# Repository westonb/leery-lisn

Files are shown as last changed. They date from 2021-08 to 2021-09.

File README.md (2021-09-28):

# leery-lisn
### A open source dual AC LISN with integrated common mode / differential mode separator and transient limiter.

**Schematic [here](doc/lisn-pcb.pdf)**

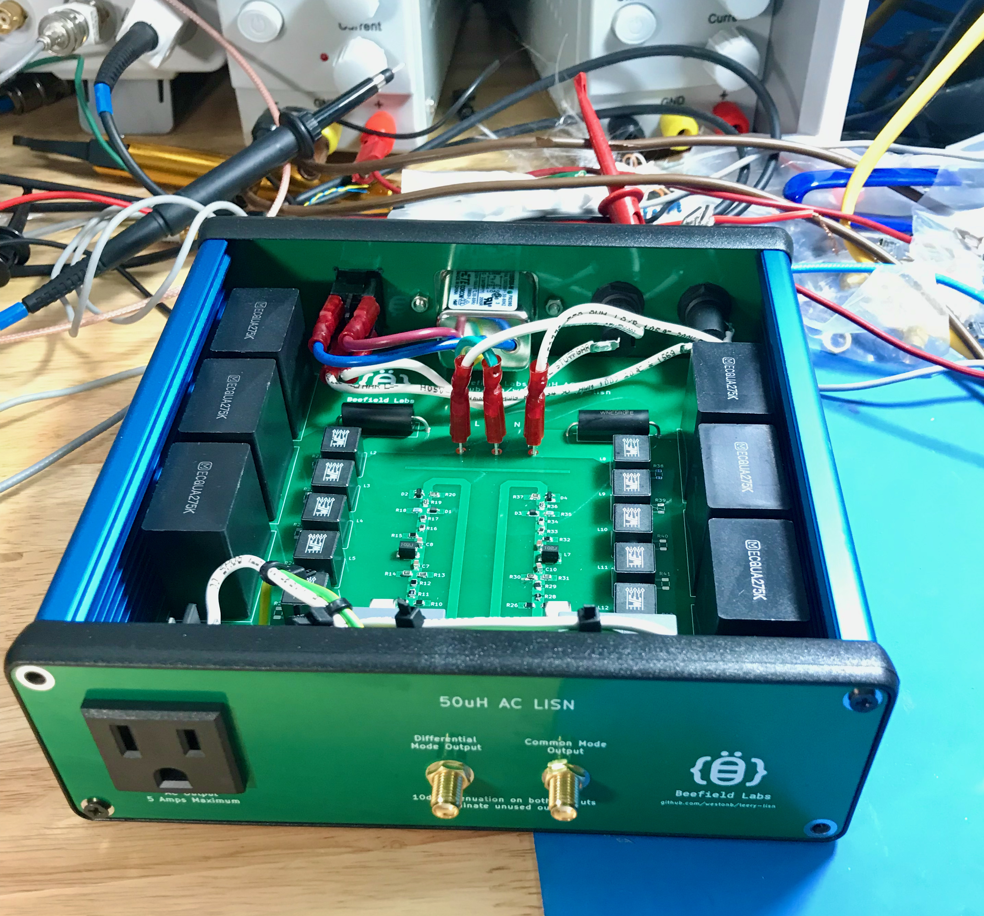
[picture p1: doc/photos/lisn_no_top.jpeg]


## Summary
The leery-lisn is a Line Impedance Stabilization Network (LISN) for pre-compliance conducted EMI measurements of devices that plug into the AC line.
A LISN goes between a device and the AC outlet and provides a known AC line impedance, allowing for repeatable measurements of conducted noise generated by the device.
It also contains circuitry to couple the noise to a 50 ohm RF output to allow for measurement with a spectrum analyzer.

The leery-lisn contains a LISN network on both the neutral and line connections of the AC plug and a common mode / differential mode separator, allowing for measurement of both the differential mode and common mode noise generated by a device.
It also contains a transient limiter to protect a connected spectrum analyzer from transients on the AC line or plugging the LISN into the AC line when the spectrum analyzer is already connected.

The design of the leery-lisn is loosely based on the LISN designs from this [thread](https://www.eevblog.com/forum/projects/5uh-lisn-for-spectrum-analyzer-emcemi-work/) on the EEVBlog forum, as well as the designs for a [common mode / differential mode separator](https://www.eevblog.com/forum/projects/diy-dm-cm-seperator-for-emc-lisn-mate/) and this [transient limiter](https://www.eevblog.com/forum/projects/transient-limiter-for-spectrum-analyzer-protection/).

## Specifications & Operation
The leery-lisn is a 50uH LISN, which is the typical impedance value for conducted emissions testing between 150KHz - 30MHz, as specified in standards such as CISPR16.
The leery-lisn is designed for a maximum input / output voltage of 240V, although the output plug is fixed as a US style 120V plug.
The current rating is 5A RMS.

Due to the transient limiter, the common mode and differential mode outputs have 10dB of attenuation.
For proper separation of the common mode and differential mode signals the unused output should be attenuated into 50 ohms.

The leery-lisn contains 8.1uF of capacitance between each AC leg and ground to decouple the LISN impedance from the impedance of the AC line.
Due to the high ground currents resulting from this capacitance, consider using a isolation transformer between the AC line and the leery-lisn.

## Performance
S21 measurements were taken of the leery-lisn to verify correct operation of the common mode / differential mode separator and impedance measurements were taken to check compliance with CISPR16 standard.

A very cursed adaptor was created to connect the AC output of the LISN to a VNA and measurements were taken with the AC input to the VNA shorted.

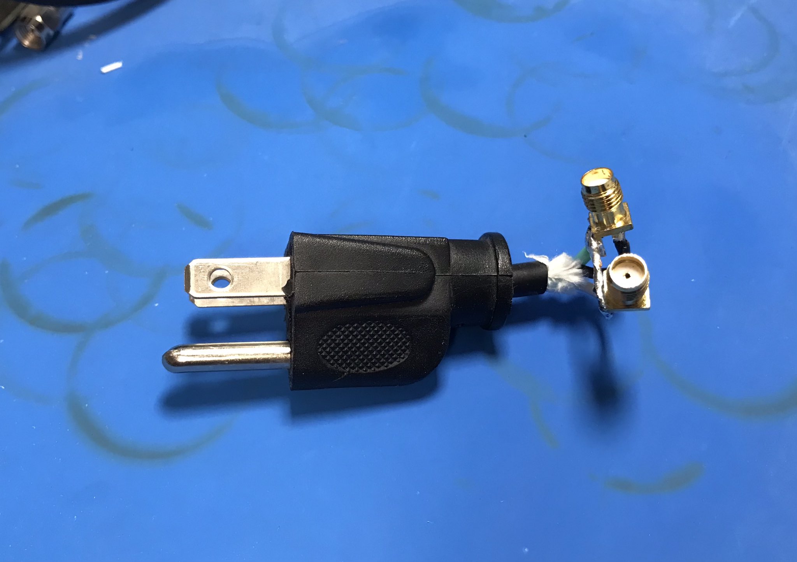
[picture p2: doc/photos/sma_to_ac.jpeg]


The leery-lisn is a three port device, so it can not be fully characterized with a two port VNA.
However, a resistive splitter allows for accurately measuring the common mode S21 and the common mode rejection.

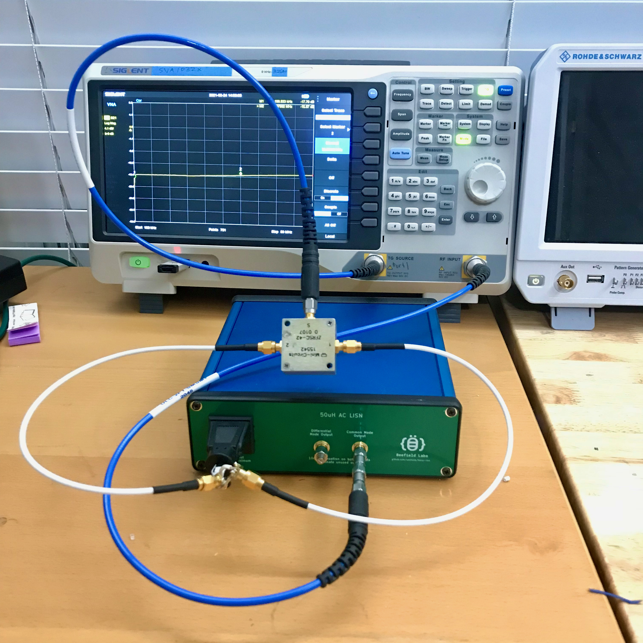
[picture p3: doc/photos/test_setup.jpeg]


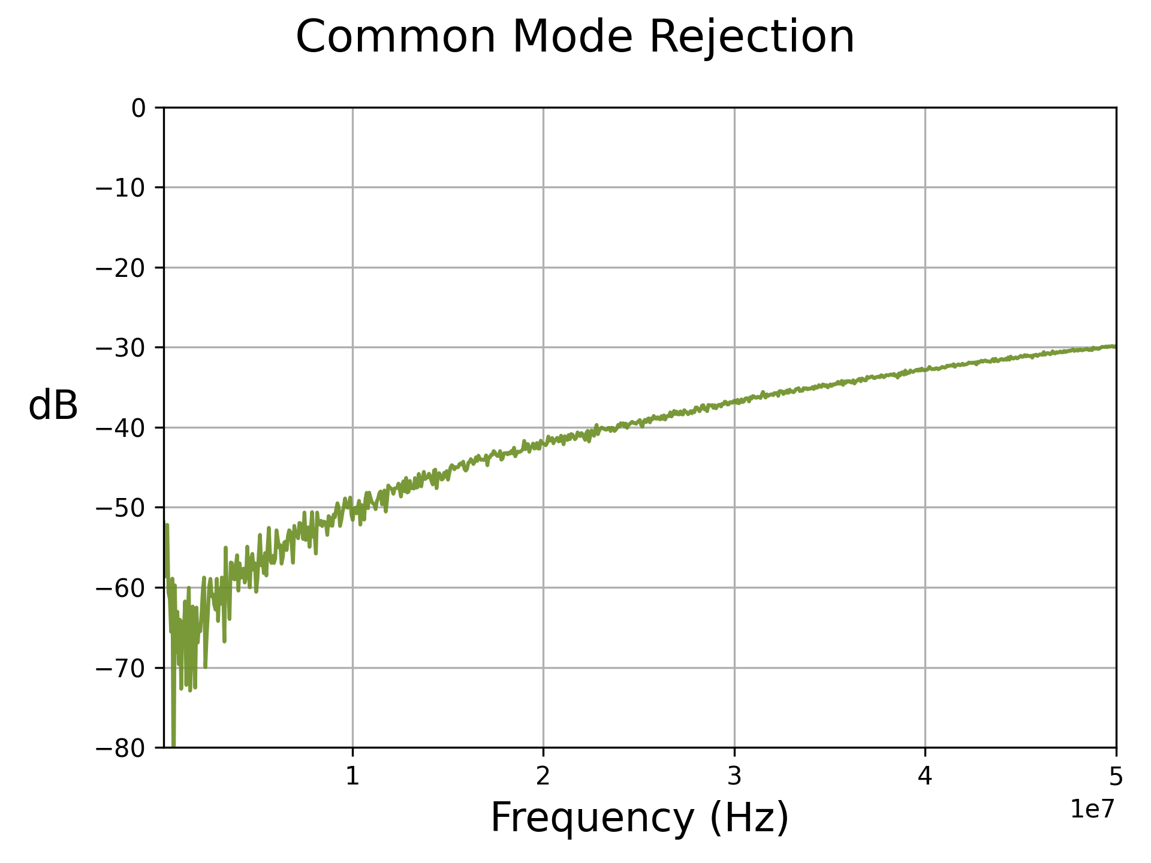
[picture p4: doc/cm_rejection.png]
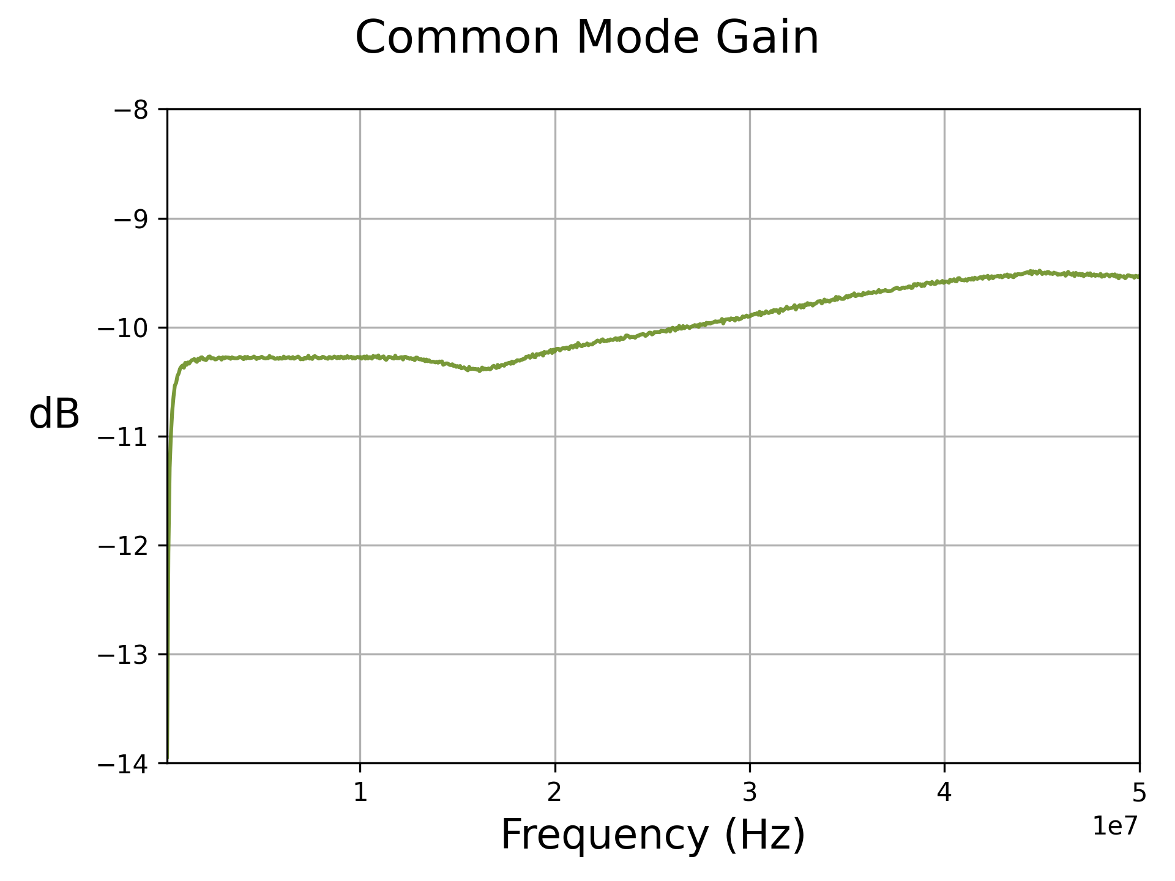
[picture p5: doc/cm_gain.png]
 

If it is assumed that driving one input to the LISN with the other terminated into 50 ohms provides a even split of common mode and differential mode stimulus, the differential mode S21 can also be measured.

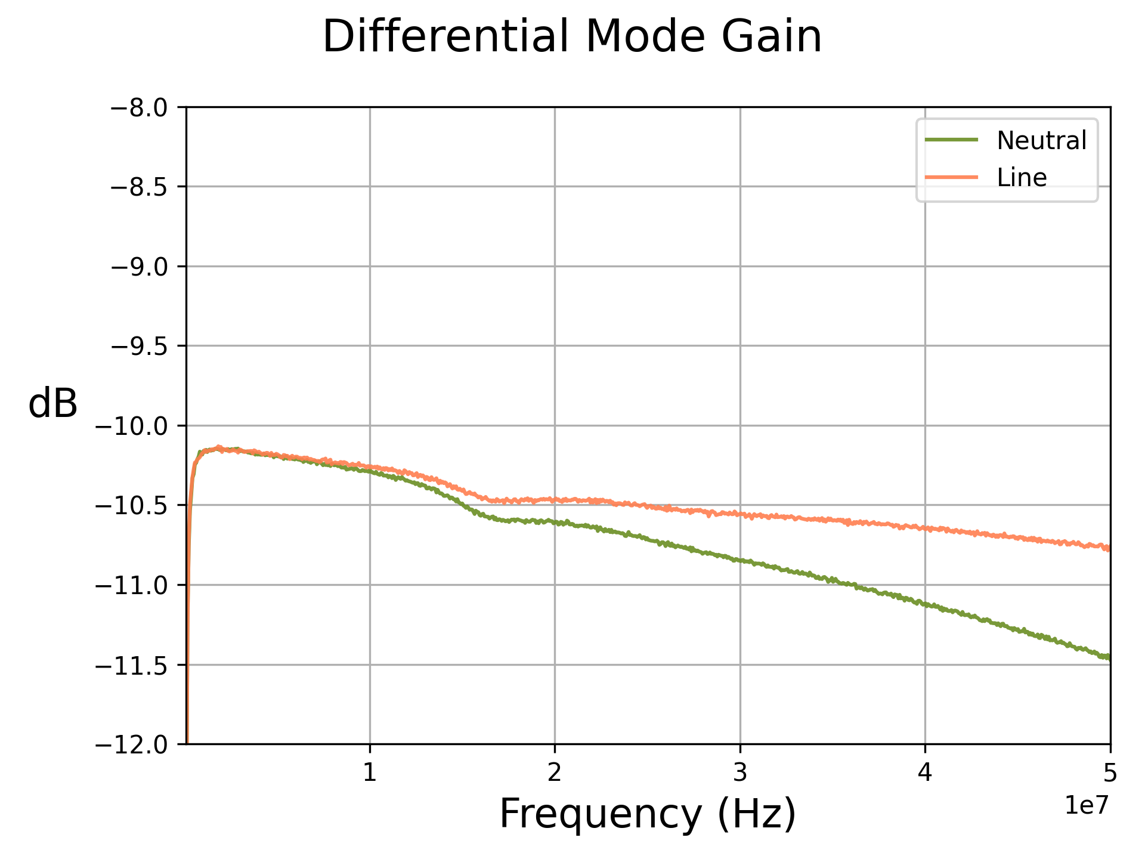
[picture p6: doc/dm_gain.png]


The impedance of the two legs can also be compared against the CISPR16 standard, which provides a table of frequency vs the allowable |Z| and phase of the LISN input impedance.
From the plot below it can be seen that the line leg of the LISN is slightly out of spec above 25MHz due to an extra 2" of wire running between the AC connector and the PCB.
This is also the cause of the difference in the differential mode response for the two inputs of the LISN.
leery-lisn technically does not meet the CISPR16 requirements, but should be close enough for pre-compliance work.
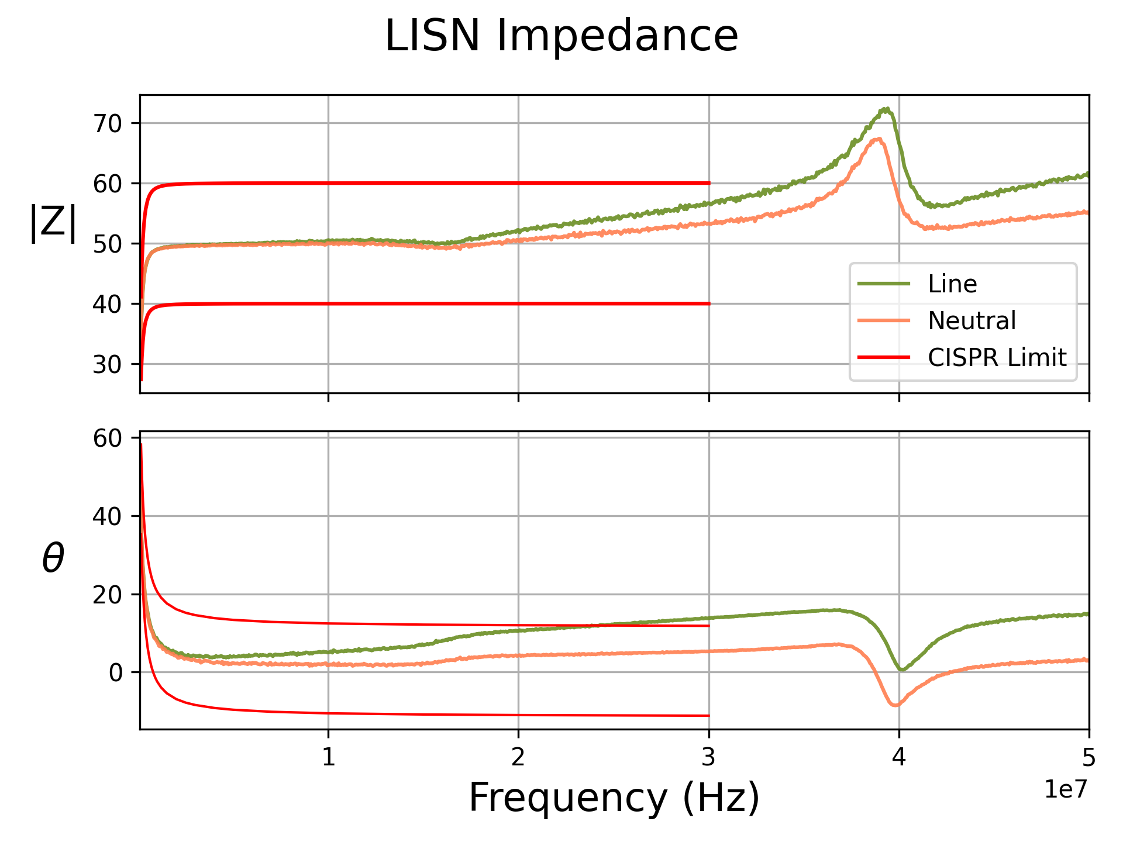
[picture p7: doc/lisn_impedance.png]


## Construction
The leery-lisn is completely open source and the PCB design for the LISN and the front and back panels are provided in this repository.

Parts not on the BOM for the PCB are:

| Description  | Quantity | Part Number |
|---|---|---|
| Enclosure | 1 | 1455T1601BU |
| Fuse Holder  | 2 | 696211001102 |
| AC Outlet | 1 | 3-119-052 |
| Power Switch | 1 | H8550VBBBEN551W |
| AC Inlet | 1 | 1-6609987-4 |

## Improvements
A bleeder resistor should be added across the input capacitors to discharge them.

The impedance of the line side of the LISN is slightly outside of the limits specified in the CISPR16 standards due to the added wire length between the AC plug on the left side of the panel and the line input on the PCB, which is on the right.
The front panel could be redone to reduce this wire length.

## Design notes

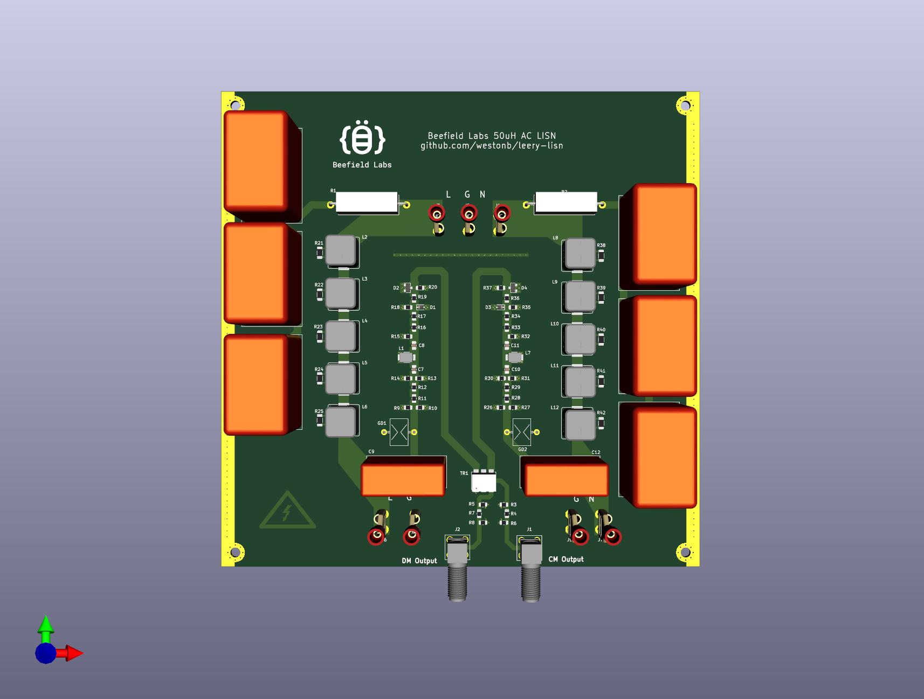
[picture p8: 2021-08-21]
doc/photos/lisn-pcb.jpg

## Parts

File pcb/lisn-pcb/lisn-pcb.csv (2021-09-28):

Ref | Qty | Value | Footprint | Description | MPN
C1, C2, C3, C4, C5, C6, | 6 | 2.7u | Capacitor_THT:C_Rect_L31.5mm_W20.0mm_P27.50mm_MKS4 | Unpolarized capacitor | ECQ-UAAF275K
C7, C8, C10, C11, | 4 | 0.47u | Capacitor_SMD:C_0805_2012Metric | Unpolarized capacitor | 08051C474K4Z2A
C9, C12, | 2 | 0.1u | Capacitor_THT:C_Rect_L26.5mm_W10.5mm_P22.50mm_MKS4 | Unpolarized capacitor | BFC233860104
D1, D3, | 2 | D_TVS | Diode_SMD:D_SOD-323 | Bidirectional transient-voltage-suppression diode | STS321050B100
D2, D4, | 2 | BAV23S | Package_TO_SOT_SMD:SOT-23 | Dual diode, anode/cathode/center | BAV23S,215
GD1, GD2, | 2 | 2045-09-BLF | wbraun_smd:GDT_Bourns_2045 | Gas Discharge Tube with 2 Pins | 2045-09-BLF
H1, H2, H3, H4, | 4 | MountingHole_Pad | wbraun_smd:M3-tight-fit-socket-head | Mounting Hole with connection
J1, J2, | 2 | Conn_Coaxial | Connector_Coaxial:SMA_Amphenol_132203-12_Horizontal | coaxial connector (BNC, SMA, SMB, SMC, Cinch/RCA, ...) | 619540-1
J3, J4, J5, J6, J7, J8, J9, | 7 | 62409-1 | wbraun_smd:62409-1 | Generic connector, single row, 01x01, script generated (kicad-library-utils/schlib/autogen/connector/) | 62409-1
L1, L7, | 2 | 1m | wbraun_smd:L_BOURNS_PM1812 | Inductor | PM1812-102J-RC
L2, L3, L4, L5, L6, L8, L9, L10, L11, L12, | 10 | 10u | wbraun_smd:L_WURTH_WE-HCC-1090 | Inductor symbol for simulation only | 7443331000
R1, R2, | 2 | 5 | Resistor_THT:R_Axial_Power_L20.0mm_W6.4mm_P25.40mm | Resistor | WNE5R0FET
R3, | 1 | 50 | Resistor_SMD:R_0805_2012Metric | Resistor | RNCP0805FTD49R9
R4, R7, | 2 | 0 | Resistor_SMD:R_0805_2012Metric | Resistor | RC0805JR-070RL
R5, R6, R8, | 3 | DNP | Resistor_SMD:R_0805_2012Metric | Resistor
R9, R26, | 2 | 620 | Resistor_SMD:R_0805_2012Metric | Resistor | RCS0805620RFKEA
R10, R27, | 2 | 560 | Resistor_SMD:R_0805_2012Metric | Resistor | RCS0805560RFKEA
R11, R28, | 2 | 10 | Resistor_SMD:R_0805_2012Metric | Resistor | RCS080510R0FKEA
R12, R29, | 2 | 7.5 | Resistor_SMD:R_0805_2012Metric | Resistor | RCS08057R50FKEA
R13, R14, R20, R30, R31, R37, | 6 | 430 | Resistor_SMD:R_0805_2012Metric | Resistor | ESR10EZPF4300
R15, R32, | 2 | 220 | Resistor_SMD:R_0805_2012Metric | Resistor | RCS0805220RFKEA
R16, R17, R33, R34, | 4 | 15 | Resistor_SMD:R_0805_2012Metric | Resistor | RCS080515R0FKEA
R18, R35, | 2 | 127 | Resistor_SMD:R_0805_2012Metric | Resistor | RK73H2ATTD1270F
R19, R36, | 2 | 12 | Resistor_SMD:R_0805_2012Metric | Resistor | ERJ-6ENF12R0V
R21, R22, R23, R24, R25, R38, R39, R40, R41, R42, | 10 | DNP | Resistor_SMD:R_1206_3216Metric | Resistor
TR1, | 1 | ADT2-71T+ | RF_Mini-Circuits:Mini-Circuits_CD637_H5.23mm | 0.40-500MHz 1:2 RF Transformer, Unbalanced to Balanced Center Tap, CD542 | ADT2-71T+

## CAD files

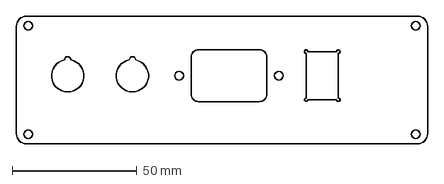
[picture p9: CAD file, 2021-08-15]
cad/rear-panel.dxf
165.0 x 51.1 mm

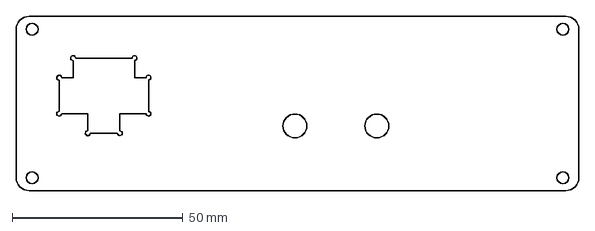
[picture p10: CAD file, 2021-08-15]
cad/front_panel.dxf
165.0 x 51.1 mm

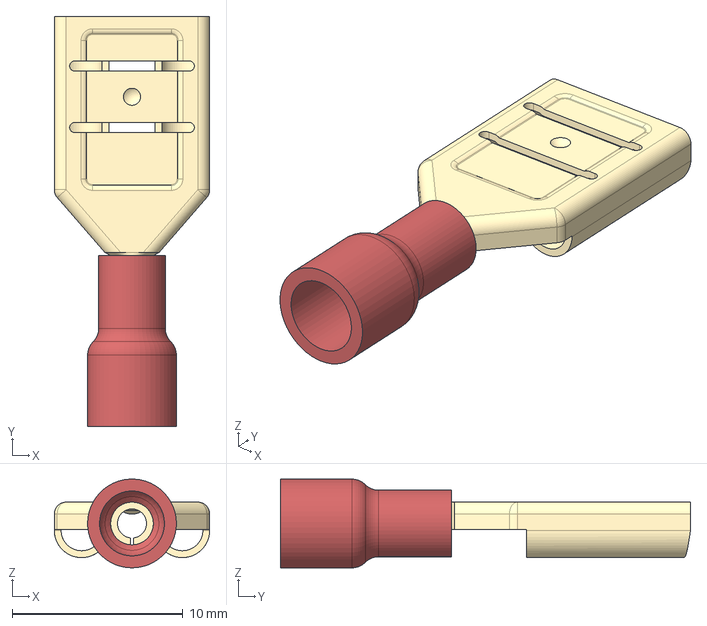
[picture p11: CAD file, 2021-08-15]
cad/FDD1.25-312.step
9.10 x 24.0 x 5.20 mm

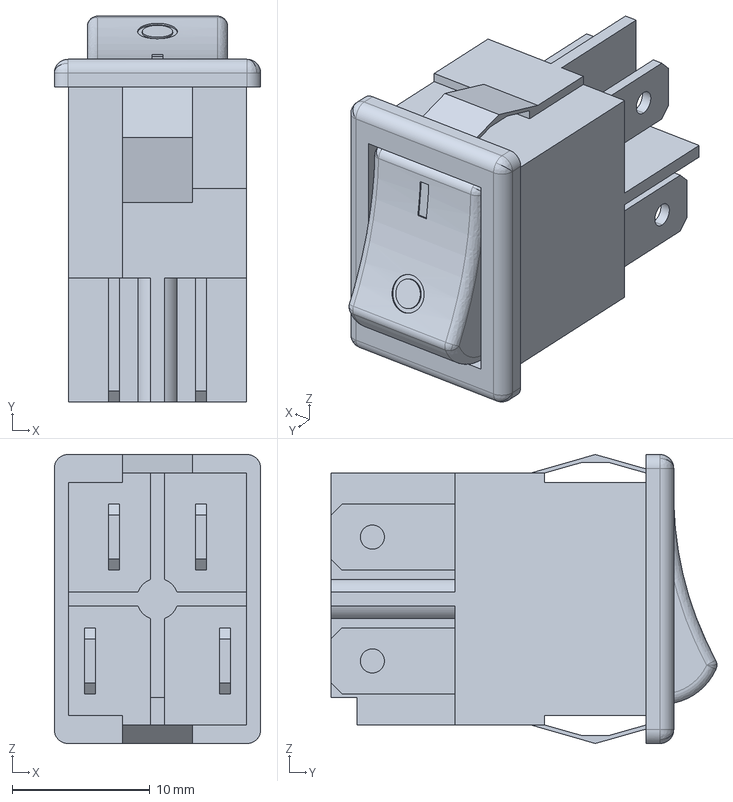
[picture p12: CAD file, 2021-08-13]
cad/h8550vb.stp
15.0 x 28.0 x 21.0 mm

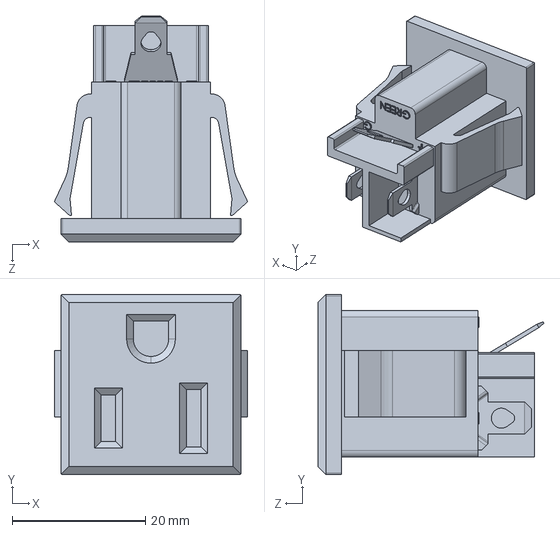
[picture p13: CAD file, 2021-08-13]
cad/NR020_3-119-052_03.STEP
29.0 x 27.0 x 33.9 mm

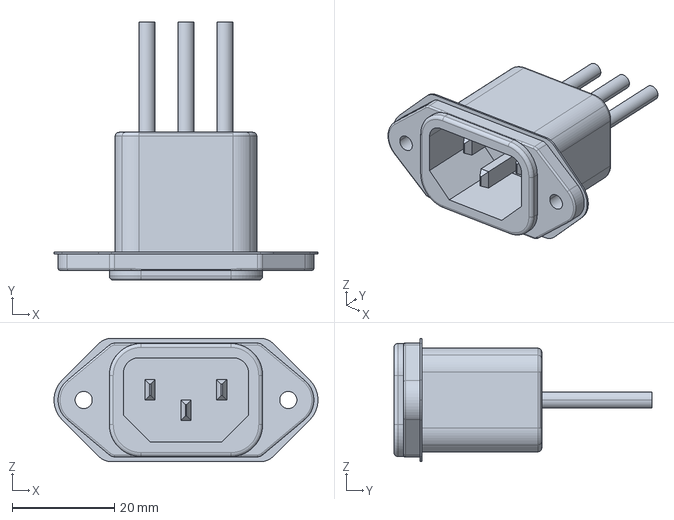
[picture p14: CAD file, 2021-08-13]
cad/c-1-6609987-4-c-3d.stp
51.6 x 50.5 x 24.1 mm

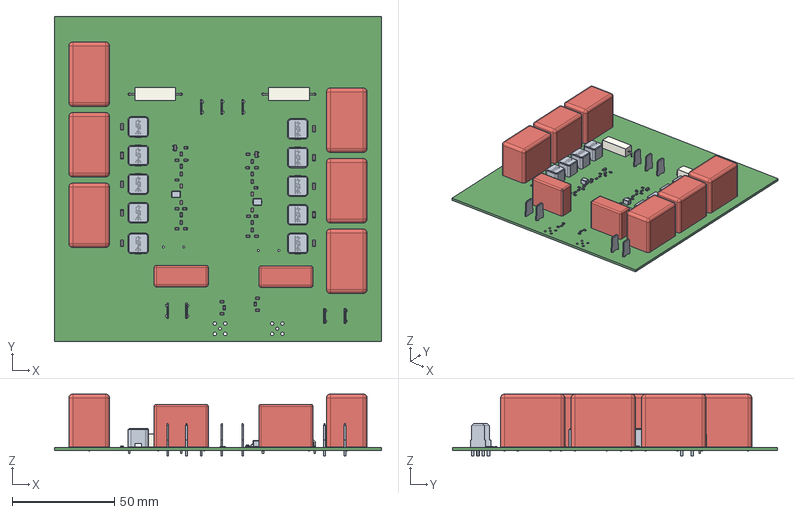
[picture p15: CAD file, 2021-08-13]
cad/lisn-pcb.step
160.0 x 159.0 x 30.3 mm

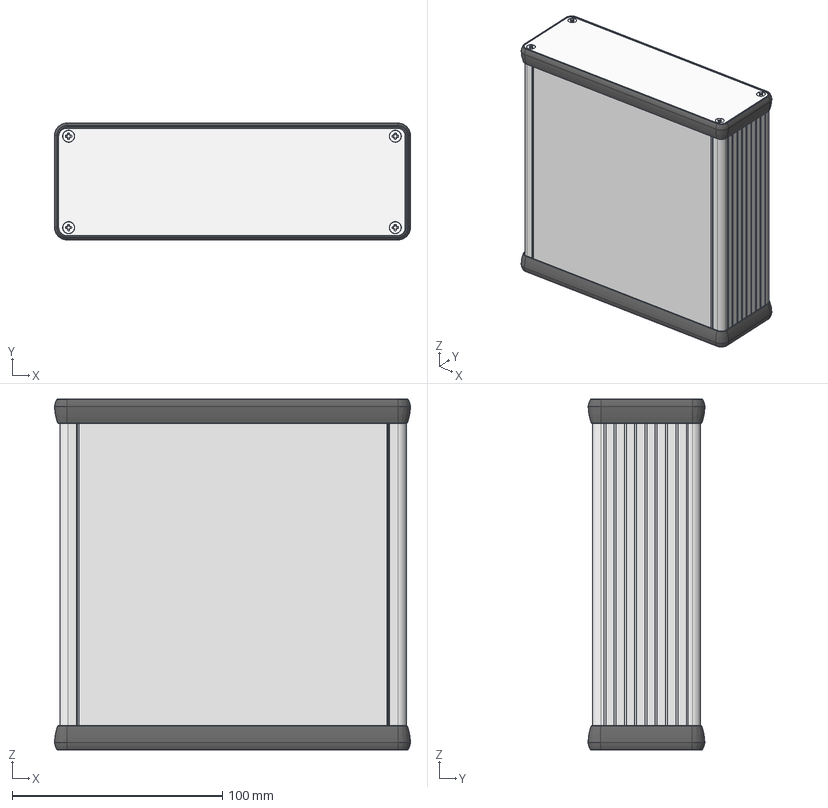
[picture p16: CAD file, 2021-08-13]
cad/1455T1601.stp
169.5 x 55.7 x 167.0 mm
T Extrusion 160mm
T Bezel Open x 2
T End Plate x 2
1455 screw x 8
T Extrusion Cap 160mm

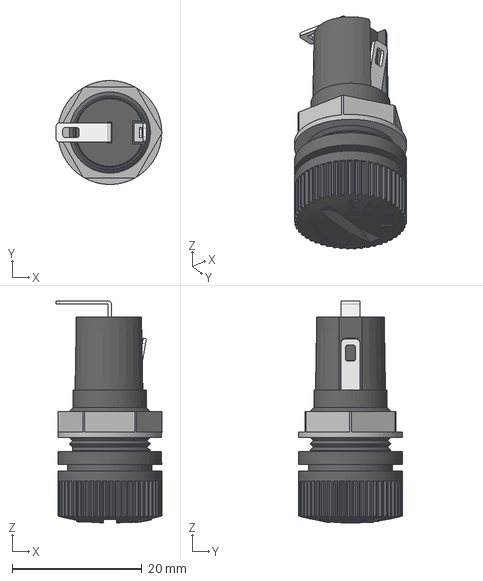
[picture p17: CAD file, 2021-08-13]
cad/696211001102 (rev1).stp
16.2 x 16.0 x 34.2 mm

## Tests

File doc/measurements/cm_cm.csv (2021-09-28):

Machine Module SVA1032X Plus
Trace Name | Trace A
Meas Type | S21
Start Frequency | +1.000000000E+05
Stop Frequency | +5.000000000E+07
Format | Log Mag
IFBW | 1.000000e+04
Trace Data
Frequency | Formatted Data
1.000000e+05 | -1.994515e+01
1.665333e+05 | -1.807263e+01
2.330667e+05 | -1.729083e+01
2.996000e+05 | -1.697734e+01
3.661333e+05 | -1.676642e+01
4.326667e+05 | -1.663557e+01
4.992000e+05 | -1.653529e+01
5.657333e+05 | -1.651054e+01
6.322667e+05 | -1.644868e+01
6.988000e+05 | -1.642300e+01
7.653333e+05 | -1.638125e+01
8.318667e+05 | -1.636231e+01
8.984000e+05 | -1.635132e+01
9.649333e+05 | -1.637223e+01
1.031467e+06 | -1.632771e+01
1.098000e+06 | -1.634573e+01
1.164533e+06 | -1.632387e+01
1.231067e+06 | -1.633439e+01
1.297600e+06 | -1.631665e+01
1.364133e+06 | -1.630406e+01
1.430667e+06 | -1.629927e+01
1.497200e+06 | -1.629247e+01
1.563733e+06 | -1.631019e+01
1.630267e+06 | -1.631878e+01
1.696800e+06 | -1.628881e+01
1.763333e+06 | -1.630286e+01
1.829867e+06 | -1.627871e+01
1.896400e+06 | -1.627715e+01
1.962933e+06 | -1.629588e+01
2.029467e+06 | -1.629513e+01
2.096000e+06 | -1.630321e+01
2.162533e+06 | -1.628895e+01
2.229067e+06 | -1.627083e+01
2.295600e+06 | -1.626863e+01
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

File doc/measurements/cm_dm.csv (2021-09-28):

Machine Module SVA1032X Plus
Trace Name | Trace A
Meas Type | S21
Start Frequency | +1.000000000E+05
Stop Frequency | +5.000000000E+07
Format | Log Mag
IFBW | 1.000000e+04
Trace Data
Frequency | Formatted Data
1.000000e+05 | -5.780670e+01
1.665333e+05 | -5.896940e+01
2.330667e+05 | -6.464450e+01
2.996000e+05 | -5.819406e+01
3.661333e+05 | -6.668643e+01
4.326667e+05 | -6.744739e+01
4.992000e+05 | -7.155812e+01
5.657333e+05 | -6.490972e+01
6.322667e+05 | -9.243432e+01
6.988000e+05 | -6.574300e+01
7.653333e+05 | -7.410221e+01
8.318667e+05 | -6.905902e+01
8.984000e+05 | -7.559867e+01
9.649333e+05 | -7.004082e+01
1.031467e+06 | -7.868059e+01
1.098000e+06 | -7.030163e+01
1.164533e+06 | -7.190010e+01
1.231067e+06 | -6.775283e+01
1.297600e+06 | -7.819937e+01
1.364133e+06 | -6.968495e+01
1.430667e+06 | -6.604848e+01
1.497200e+06 | -7.891120e+01
1.563733e+06 | -7.551972e+01
1.630267e+06 | -6.839563e+01
1.696800e+06 | -7.089995e+01
1.763333e+06 | -7.853969e+01
1.829867e+06 | -6.852621e+01
1.896400e+06 | -7.290370e+01
1.962933e+06 | -7.069411e+01
2.029467e+06 | -7.149278e+01
2.096000e+06 | -6.925965e+01
2.162533e+06 | -6.633572e+01
2.229067e+06 | -6.477965e+01
2.295600e+06 | -7.598300e+01
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

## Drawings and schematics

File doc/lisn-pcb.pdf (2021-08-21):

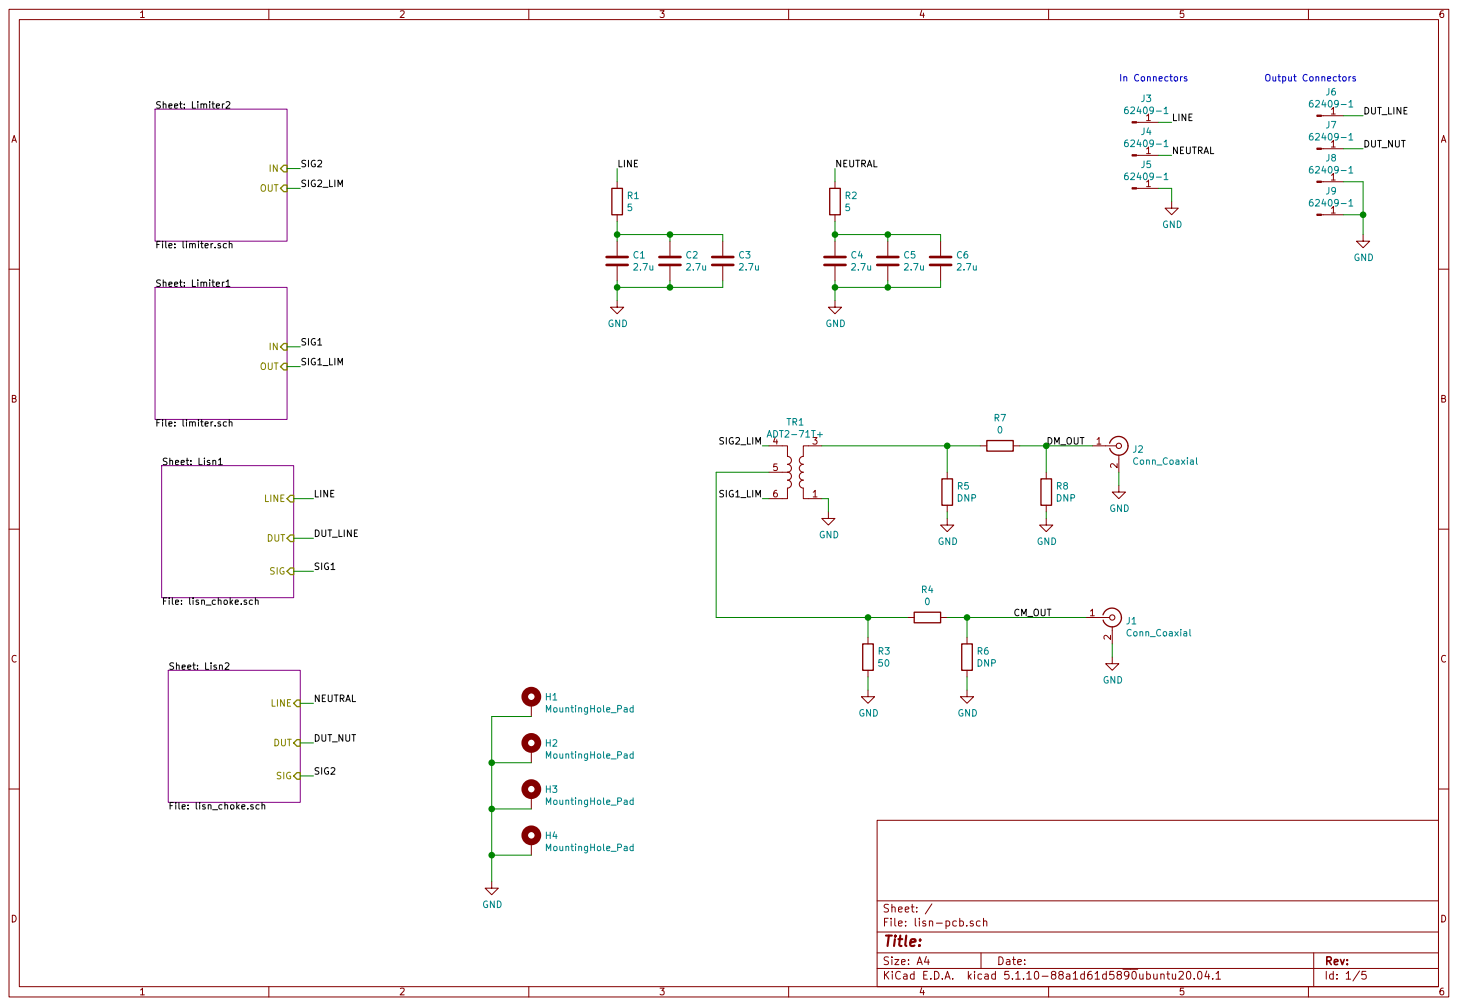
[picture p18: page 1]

File: lisn-pcb.sch Sheet: /
Id: 1/5 Title:

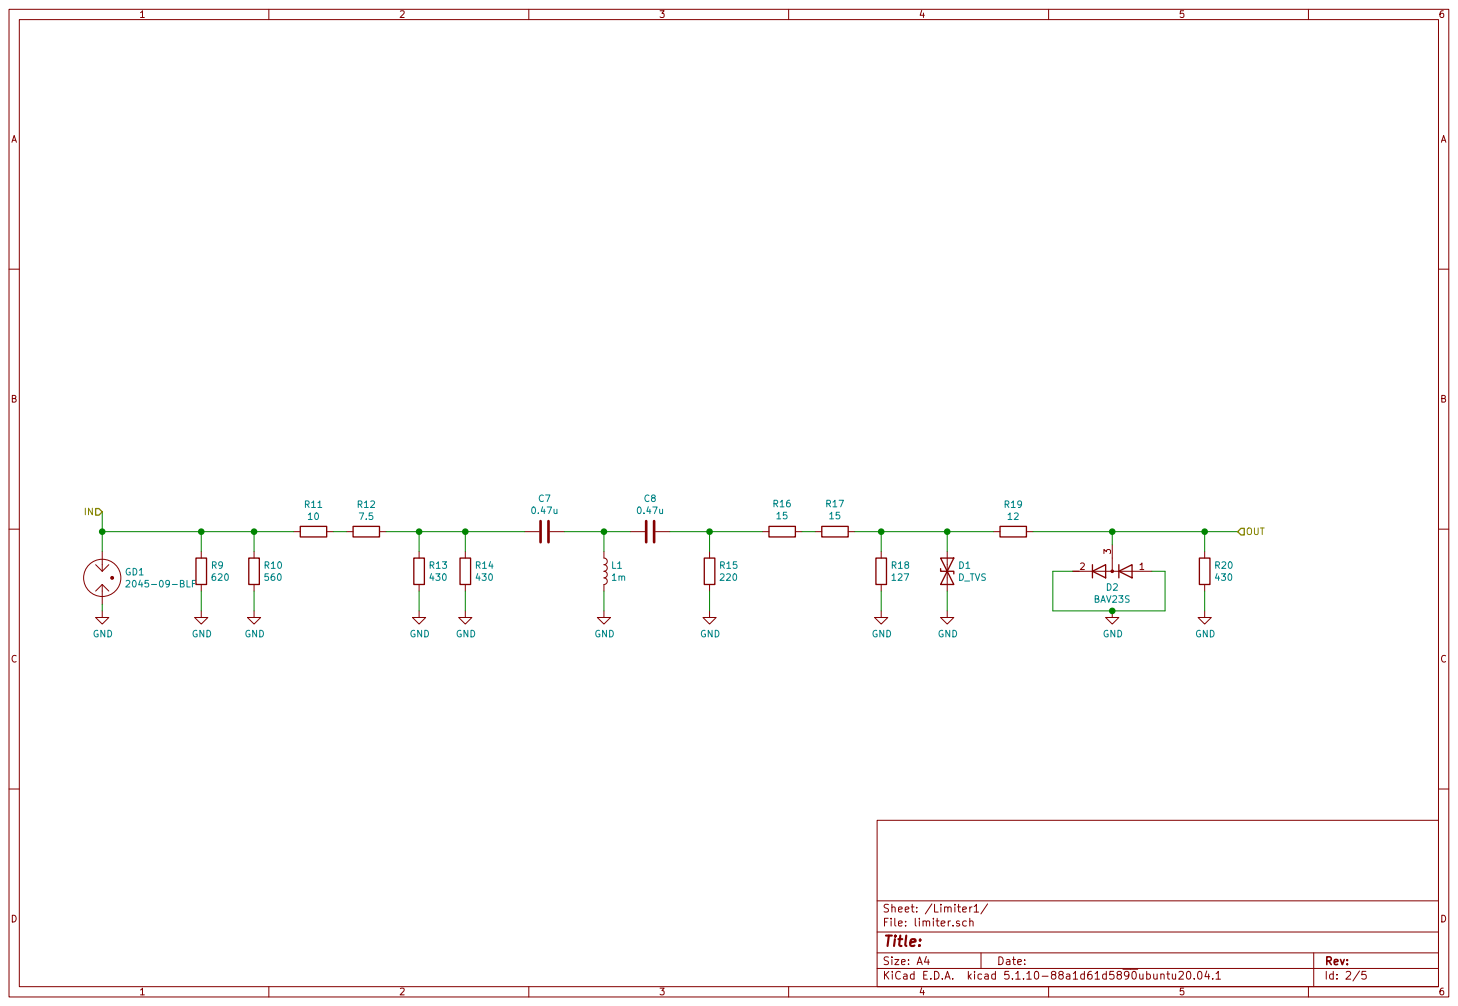
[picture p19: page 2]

Id: 2/5 Title: File: limiter.sch Sheet: /Limiter1/ R10

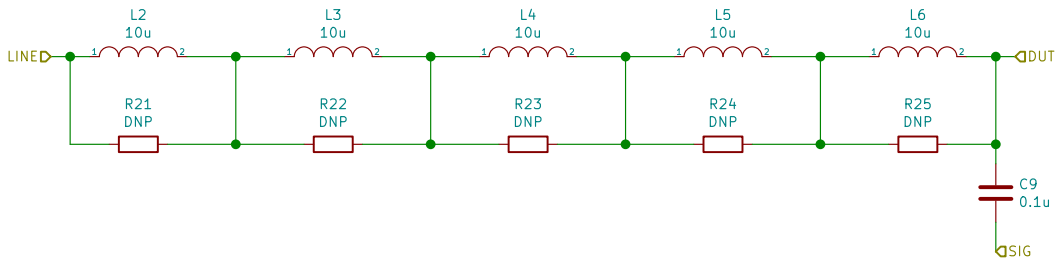
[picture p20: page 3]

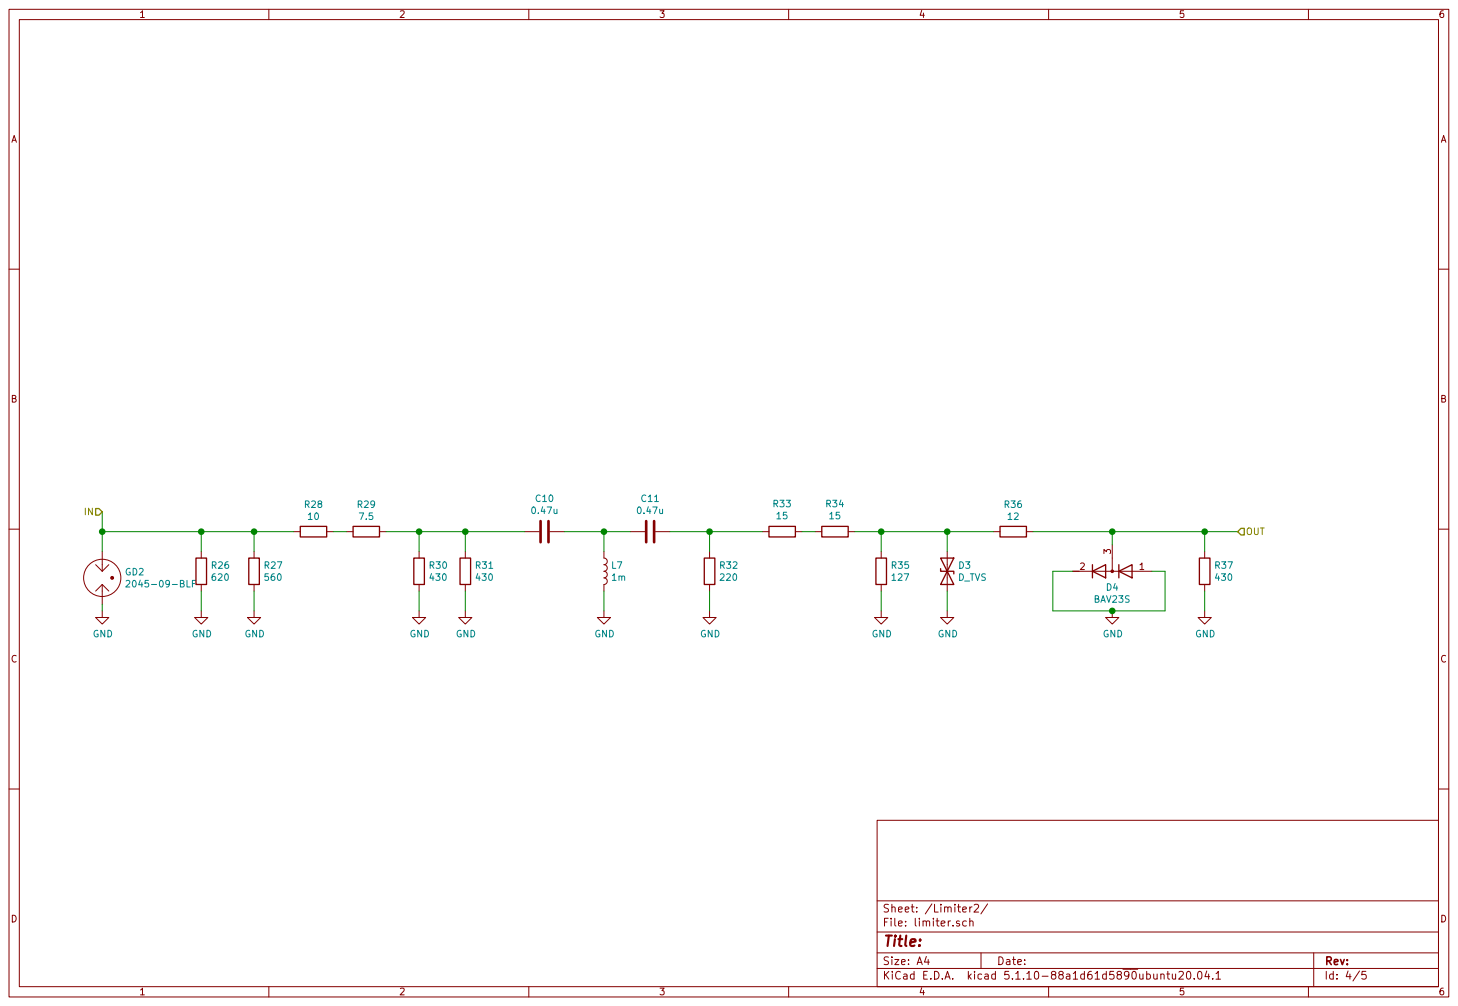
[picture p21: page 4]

Id: 4/5 Title: File: limiter.sch Sheet: /Limiter2/ R27

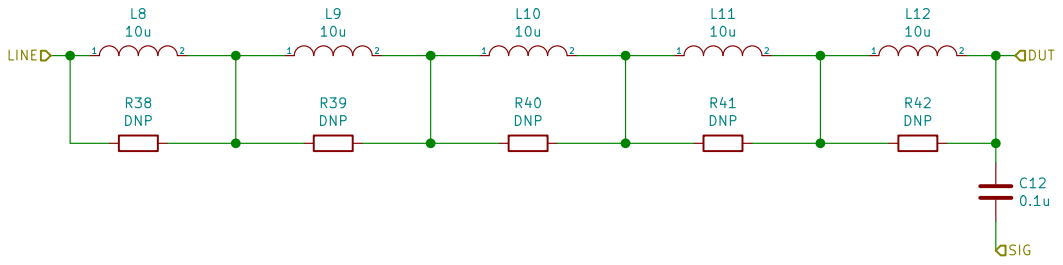
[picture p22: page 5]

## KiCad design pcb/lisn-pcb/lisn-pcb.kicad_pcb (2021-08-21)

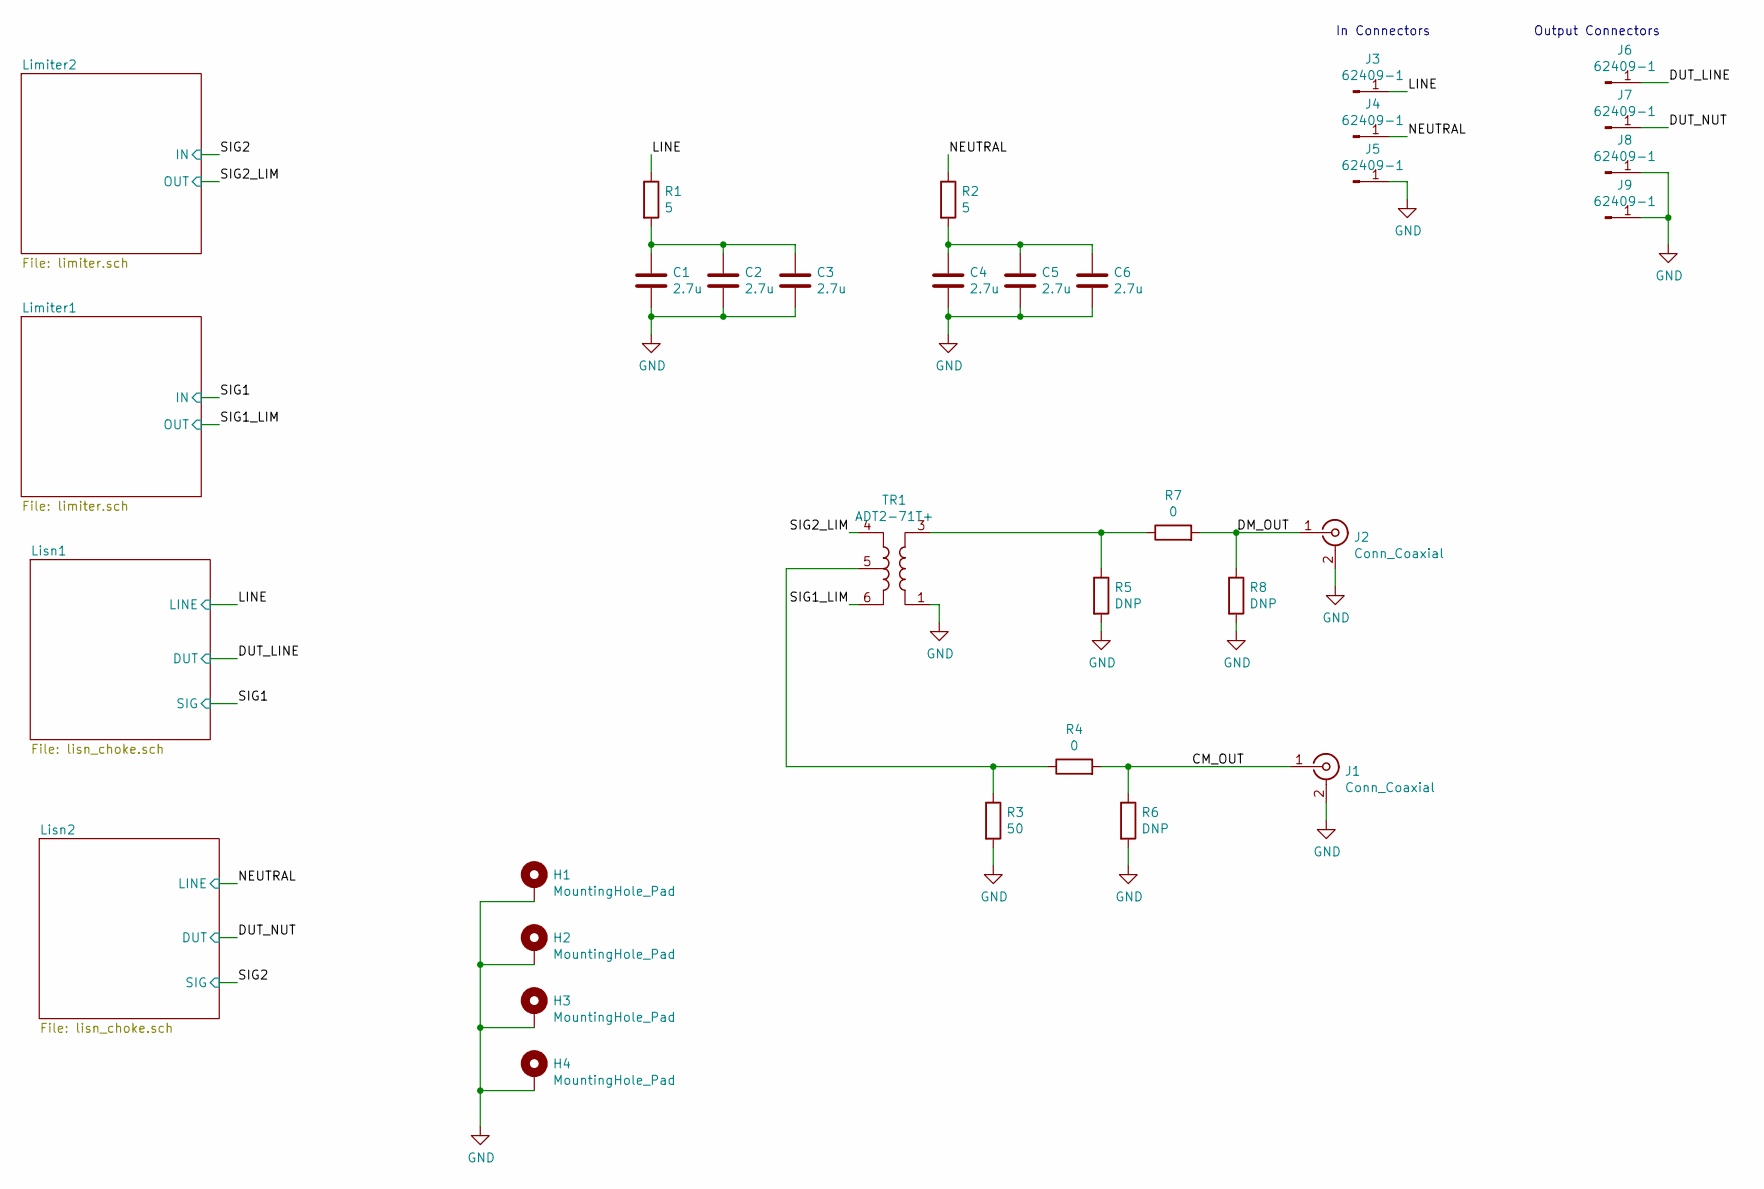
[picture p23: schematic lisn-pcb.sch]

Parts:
C1, C2, C3, C4, C5, C6: 2.7u; C_Rect_L31.5mm_W20.0mm_P27.50mm_MKS4; MPN ECQ-UAAF275K
H1, H2, H3, H4: MountingHole_Pad; M3-tight-fit-socket-head
J1, J2: Conn_Coaxial; SMA_Amphenol_132203-12_Horizontal; MPN 619540-1
J3, J4, J5, J6, J7, J8, J9: 62409-1; MPN 62409-1
R1, R2: 5; R_Axial_Power_L20.0mm_W6.4mm_P25.40mm; MPN WNE5R0FET
R3: 50; R_0805_2012Metric; MPN RNCP0805FTD49R9
R4, R7: 0; R_0805_2012Metric; MPN RC0805JR-070RL
R5, R6, R8: DNP; R_0805_2012Metric
TR1: ADT2-71T+; Mini-Circuits_CD637_H5.23mm; MPN ADT2-71T+

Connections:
/CM_OUT: J1.1 (In), R4.2, R6.1
/DM_OUT: J2.1 (In), R7.2, R8.1
/DUT_LINE: J6.1; also elsewhere on the board
/DUT_NUT: J7.1; also elsewhere on the board
/LINE: J3.1, R1.1; also elsewhere on the board
/NEUTRAL: J4.1, R2.1; also elsewhere on the board
/SIG1_LIM: TR1.6; also elsewhere on the board
/SIG2_LIM: TR1.4; also elsewhere on the board
GND: C1.2, C2.2, C3.2, C4.2, C5.2, C6.2, H1.1, H2.1, H3.1, H4.1, J1.2 (Ext), J2.2 (Ext), J5.1, J8.1, J9.1, R3.2, R5.2, R6.2, R8.2, TR1.1; also elsewhere on the board
unnamed: C1.1, C2.1, C3.1, R1.2
unnamed: C4.1, C5.1, C6.1, R2.2
unnamed: R3.1, R4.1, TR1.5
unnamed: R5.1, R7.1, TR1.3

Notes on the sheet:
In Connectors
Output Connectors

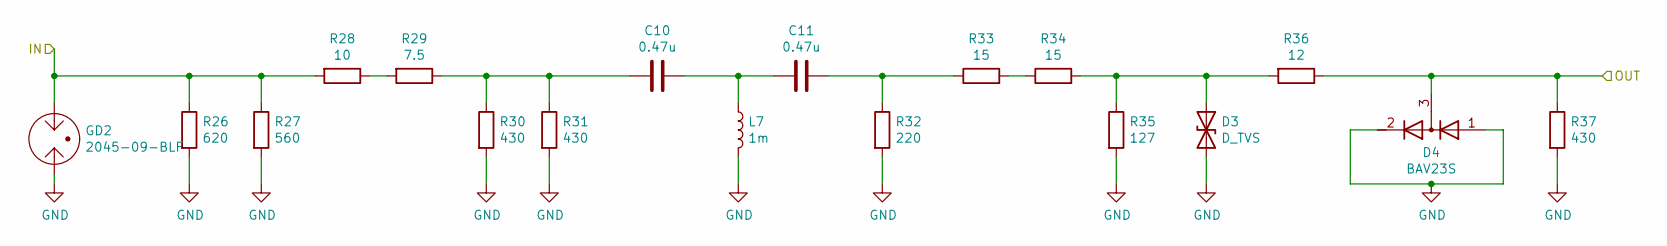
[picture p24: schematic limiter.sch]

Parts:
C7, C8: 0.47u; C_0805_2012Metric; MPN 08051C474K4Z2A
D1: D_TVS; D_SOD-323; MPN STS321050B100
D2: BAV23S; SOT-23; MPN BAV23S,215
GD1: 2045-09-BLF; GDT_Bourns_2045; MPN 2045-09-BLF
L1: 1m; L_BOURNS_PM1812; MPN PM1812-102J-RC
R9: 620; R_0805_2012Metric; MPN RCS0805620RFKEA
R10: 560; R_0805_2012Metric; MPN RCS0805560RFKEA
R11: 10; R_0805_2012Metric; MPN RCS080510R0FKEA
R12: 7.5; R_0805_2012Metric; MPN RCS08057R50FKEA
R13, R14, R20: 430; R_0805_2012Metric; MPN ESR10EZPF4300
R15: 220; R_0805_2012Metric; MPN RCS0805220RFKEA
R16, R17: 15; R_0805_2012Metric; MPN RCS080515R0FKEA
R18: 127; R_0805_2012Metric; MPN RK73H2ATTD1270F
R19: 12; R_0805_2012Metric; MPN ERJ-6ENF12R0V

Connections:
/SIG1: GD1.1, R9.1, R10.1, R11.2; also elsewhere on the board
/SIG1_LIM: D2.3 (common), R19.1, R20.1; also elsewhere on the board
GND: D1.2 (A2), D2.1 (A), D2.2 (K), GD1.2, L1.2, R9.2, R10.2, R13.2, R14.2, R15.2, R18.2, R20.2; also elsewhere on the board
unnamed: C7.1, C8.2, L1.1
unnamed: C7.2, R12.1, R13.1, R14.1
unnamed: C8.1, R15.1, R16.1
unnamed: D1.1 (A1), R17.2, R18.1, R19.2
unnamed: R11.1, R12.2
unnamed: R16.2, R17.1

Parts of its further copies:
C10, C11: 0.47u; C_0805_2012Metric; MPN 08051C474K4Z2A
D3: D_TVS; D_SOD-323; MPN STS321050B100
D4: BAV23S; SOT-23; MPN BAV23S,215
GD2: 2045-09-BLF; GDT_Bourns_2045; MPN 2045-09-BLF
L7: 1m; L_BOURNS_PM1812; MPN PM1812-102J-RC
R26: 620; R_0805_2012Metric; MPN RCS0805620RFKEA
R27: 560; R_0805_2012Metric; MPN RCS0805560RFKEA
R28: 10; R_0805_2012Metric; MPN RCS080510R0FKEA
R29: 7.5; R_0805_2012Metric; MPN RCS08057R50FKEA
R30, R31, R37: 430; R_0805_2012Metric; MPN ESR10EZPF4300
R32: 220; R_0805_2012Metric; MPN RCS0805220RFKEA
R33, R34: 15; R_0805_2012Metric; MPN RCS080515R0FKEA
R35: 127; R_0805_2012Metric; MPN RK73H2ATTD1270F
R36: 12; R_0805_2012Metric; MPN ERJ-6ENF12R0V

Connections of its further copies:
/SIG2: GD2.1, R26.1, R27.1, R28.2; also elsewhere on the board
/SIG2_LIM: D4.3 (common), R36.1, R37.1; also elsewhere on the board
GND: D3.2 (A2), D4.1 (A), D4.2 (K), GD2.2, L7.2, R26.2, R27.2, R30.2, R31.2, R32.2, R35.2, R37.2; also elsewhere on the board
unnamed: C10.1, C11.2, L7.1
unnamed: C10.2, R29.1, R30.1, R31.1
unnamed: C11.1, R32.1, R33.1
unnamed: D3.1 (A1), R34.2, R35.1, R36.2
unnamed: R28.1, R29.2
unnamed: R33.2, R34.1

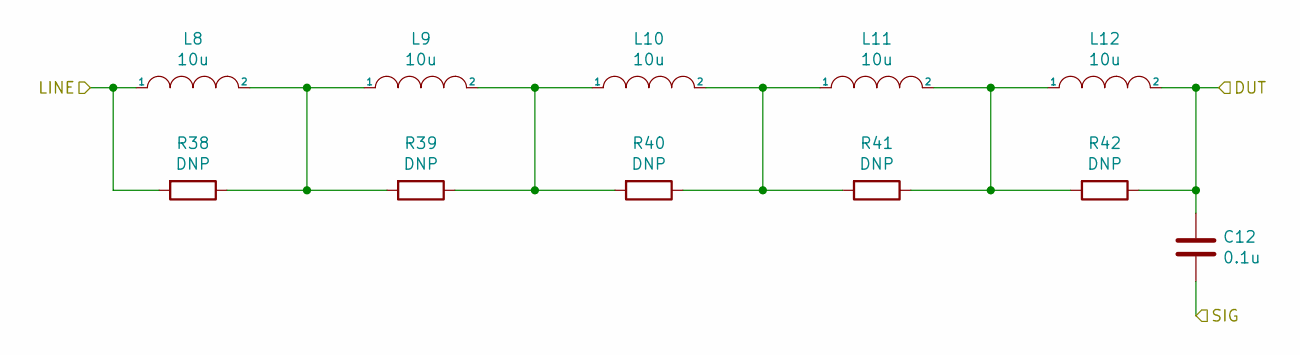
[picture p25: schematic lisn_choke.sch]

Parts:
C9: 0.1u; C_Rect_L26.5mm_W10.5mm_P22.50mm_MKS4; MPN BFC233860104
L2, L3, L4, L5, L6: 10u; L_WURTH_WE-HCC-1090; MPN 7443331000
R21, R22, R23, R24, R25: DNP; R_1206_3216Metric

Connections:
/DUT_LINE: C9.1, L6.2, R25.1; also elsewhere on the board
/LINE: L2.1, R21.2; also elsewhere on the board
/SIG1: C9.2; also elsewhere on the board
unnamed: L2.2, L3.1, R21.1, R22.2
unnamed: L3.2, L4.1, R22.1, R23.2
unnamed: L4.2, L5.1, R23.1, R24.2
unnamed: L5.2, L6.1, R24.1, R25.2

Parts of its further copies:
C12: 0.1u; C_Rect_L26.5mm_W10.5mm_P22.50mm_MKS4; MPN BFC233860104
L8, L9, L10, L11, L12: 10u; L_WURTH_WE-HCC-1090; MPN 7443331000
R38, R39, R40, R41, R42: DNP; R_1206_3216Metric

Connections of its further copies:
/DUT_NUT: C12.1, L12.2, R42.1; also elsewhere on the board
/NEUTRAL: L8.1, R38.2; also elsewhere on the board
/SIG2: C12.2; also elsewhere on the board
unnamed: L8.2, L9.1, R38.1, R39.2
unnamed: L9.2, L10.1, R39.1, R40.2
unnamed: L10.2, L11.1, R40.1, R41.2
unnamed: L11.2, L12.1, R41.1, R42.2

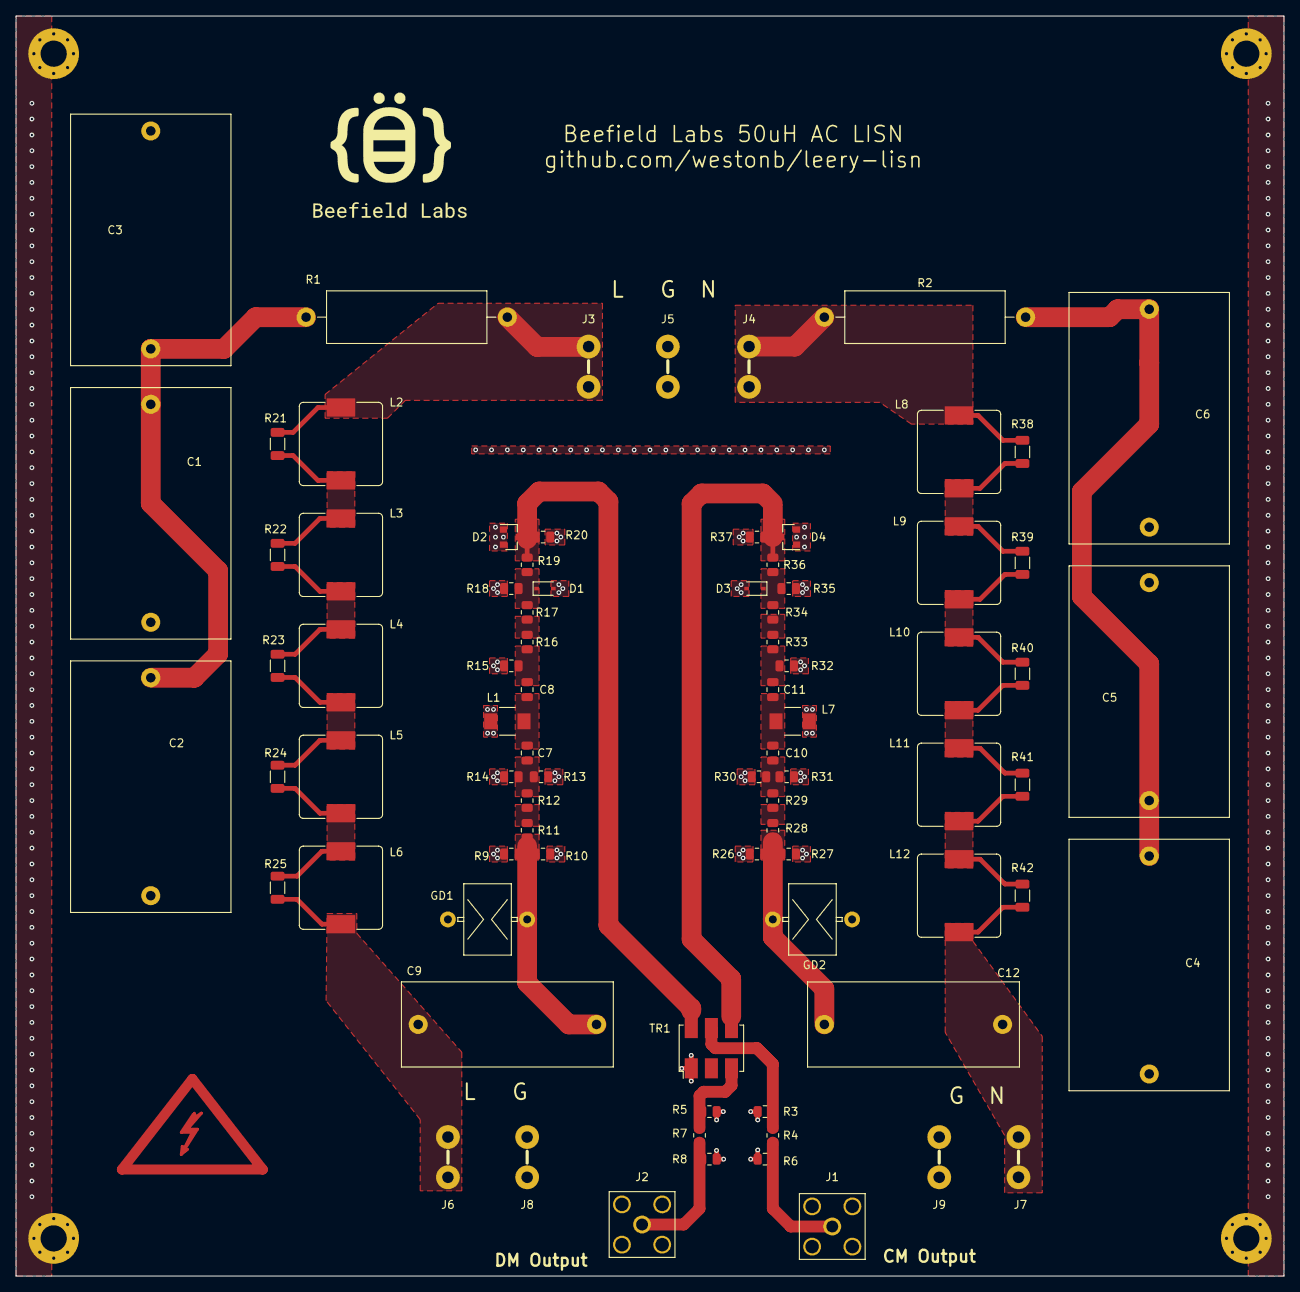
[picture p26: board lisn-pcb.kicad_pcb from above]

Board: 2 copper layers, 160.0 x 159.0 mm, 86 parts (0 on the bottom side), 35 nets.

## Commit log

2021-08-09 inital schematic and sims
    [limiter.sch, lisn-pcb.kicad_pcb, lisn-pcb.sch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]
2021-08-13 added mcad
    [1455T1601.stp, 696211001102 (rev1).stp, NR020_3-119-052_03.STEP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]
2021-08-15 finished PCB routing
    [FDD1.25-312.step, lisn-pcb.kicad_pcb, lisn-pcb.sch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]
2021-08-15 generated front and back panel dxf outlines
    [front_panel.dxf, rear-panel.dxf]
2021-08-21 V1 pcb design finished
    [front-panel-B_Cu.gbr, front-panel-B_Mask.gbr, front-panel-B_SilkS.gbr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]
2021-09-28 added LISN impedance and S21 measurements
    [cm_cm.csv, cm_dm.csv, l_dm.csv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]
2021-09-28 updated plots and readme
    [cispr16_impedances.csv]
